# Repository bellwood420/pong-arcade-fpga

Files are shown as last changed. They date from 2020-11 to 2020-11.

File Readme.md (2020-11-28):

# Arcade Pong(1972) on FPGA
Original arcade version Pong(1972) by Atari implemented on FPGA with external analog circuit. 

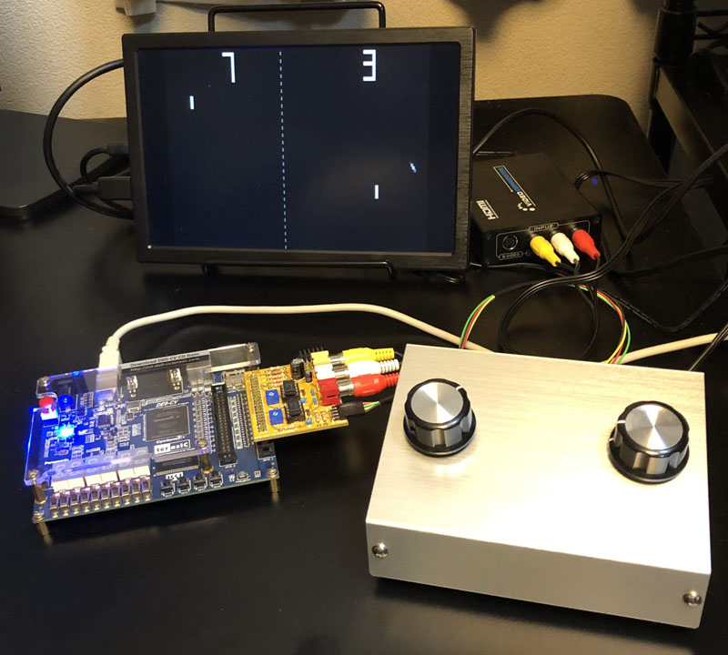
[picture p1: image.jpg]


# Features

## 1. Synchronous drive

The original circuit consists of so many asynchronous aspects, causing unstability both in routing and running on FPGA.  

To avoid it, I implemented whole circuit synchronously by treating clock signals to registers as datapaths for edge detection,
and driving them by main clock.  

This technique is introduced in the [Reference 1](#References)

## 2. Real paddle input

LMC555 and potentiometer on external circuit provide realistic paddle experience.  

Conversely, you cannnot play without them...😇

## 3. Analog video & sound output

RCA connectors on external circuit output NTSC spec video signal and line level sound signal.  

It would be nice to output video signal from VGA connector on typical FPGA boards, but I'm not good enough to make upscaler. 

# Requirements

## External analog circuit
**You need external analog circuit** other than FPGA board to play the game.
- Schematic availabe: pcb/ext-board/ext-board.pdf
- PCB gerber files available: pcb/ext-board/gerber/
- You can build it on breadboard, universal board or use my PCB.
- PCB has 40-pins GPIO connector for Terasic FPGA boards and 12-pins Pmod connector for Digilent FPGA boards.

## FPGA board

Example project files available for the boards below:

<table>
  <tr>
    <th align="left">Board</th>
    <th align="left">Terasic<br>DE0-CV</th>
    <th align="left">Terasic<br>DE-10 Nano</th>
    <th align="left">Digilent<br>Nexys4 DDR</th>
    <th></th>
  </tr>
  <tr>
    <td>Chip</td>
    <td colspan="2">Intel/Altera Cyclone V</td>
    <td>Xilinx Artix-7</td>
    <td></td>
  </tr>
  <tr>
    <td>IDE version</td>
    <td colspan="2">Quartus Prime Lite Edition 20.1</td>
    <td>Vivado 2020.1</td>
    <td></td>
  </tr>
  <tr>
    <td>Start button<br>(COIN_SW)</td>
    <td colspan="2">KEY0</td>
    <td>BTNC</td>
    <td></td>
  </tr>
  <tr>
    <td>Max point sel<br>(SW1A/SW1B)</td>
    <td colspan="3">SW[0]/SW[1]</td>
    <td>On: 15 pts, Off 11 pts</td>
  </tr>
  <tr>
    <td>Connector</td>
    <td>GPIO1</td>
    <td>GPIO0</td>
    <td>Pmod A</td>
    <td>See schematics or qsf/xdc for details</td>
  </tr>
</table>

# References
Without the following documents, I would not have been able to finish this project and understand the mystery of a video game built only on discrete logic ICs. 

1. Stephen A. Edwards. Reconstructing Pong on an FPGA. 2012.  
  http://www.cs.columbia.edu/~sedwards/papers/edwards2012reconstructing.pdf
2. Hugo R. Holden. ATARI PONG E CIRCUIT ANALYSIS & LAWN TENNIS: BUILDING A DIGITAL VIDEO GAME WITH 74 SERIES TTL IC’s. 2013.  
  http://worldphaco.com/uploads/LAWN_TENNIS.pdf

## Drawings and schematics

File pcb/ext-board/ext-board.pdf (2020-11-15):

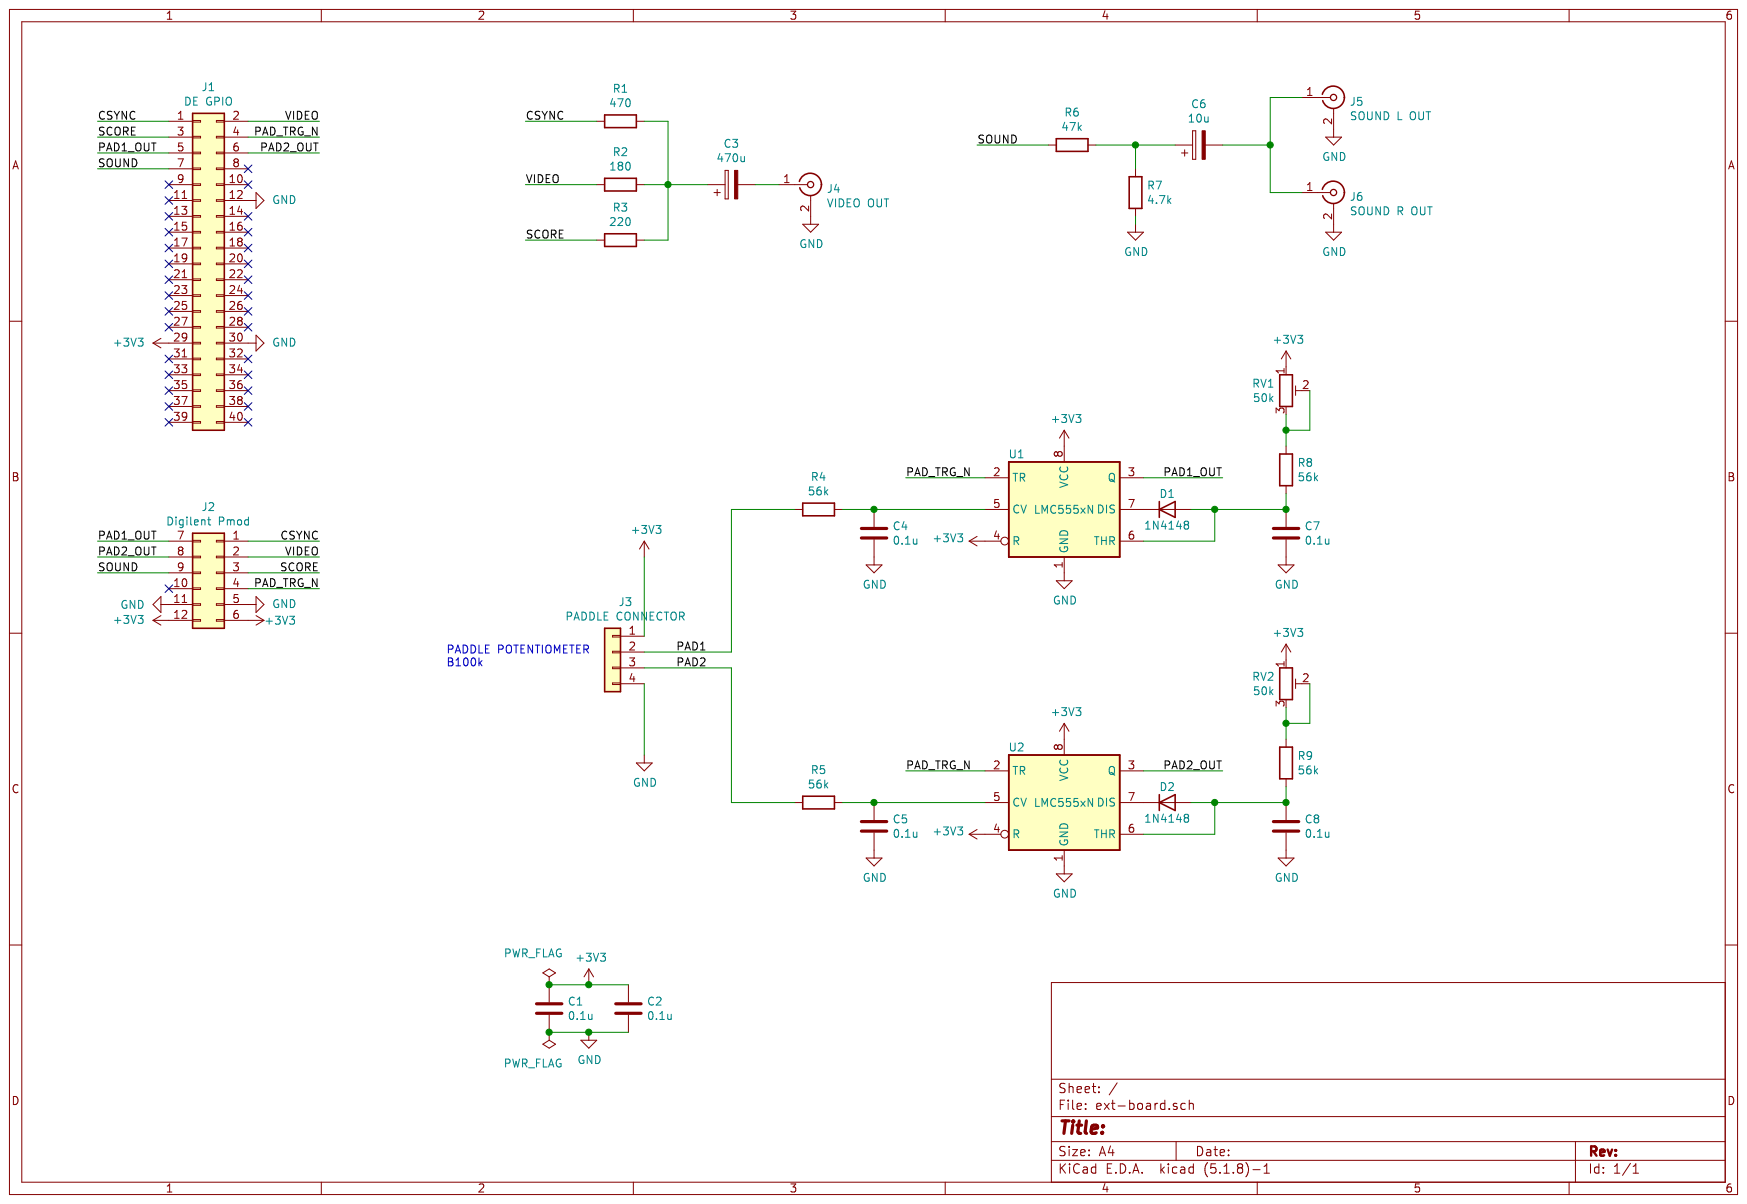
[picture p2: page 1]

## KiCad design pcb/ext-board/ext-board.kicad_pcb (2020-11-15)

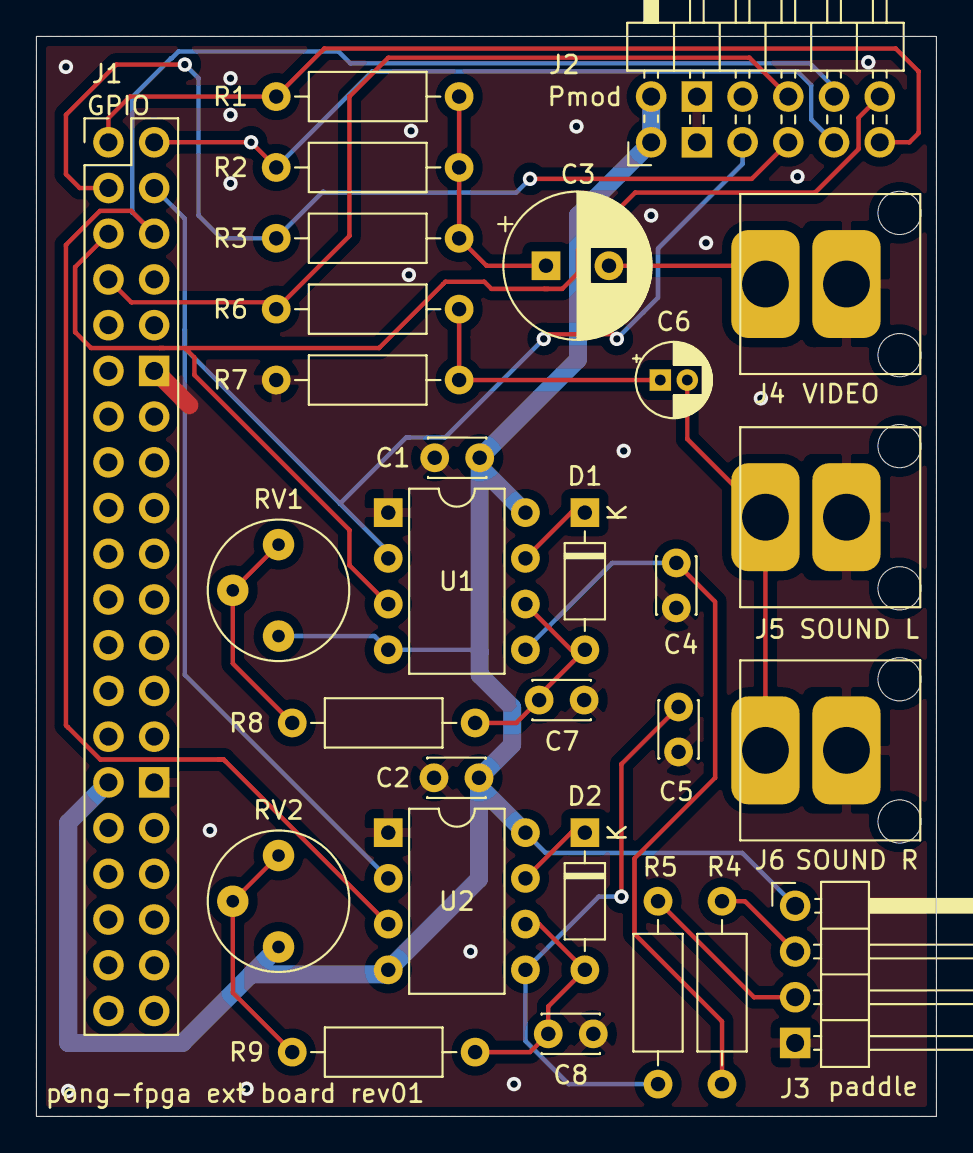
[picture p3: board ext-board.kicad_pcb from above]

Board: 2 copper layers, 50.0 x 60.0 mm, 29 parts (0 on the bottom side), 23 nets.

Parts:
C1, C2, C4, C5, C7, C8: 0.1u; C_Disc_D3.0mm_W2.0mm_P2.50mm
C3: 470u; CP_Radial_D8.0mm_P3.50mm
C6: 10u; CP_Radial_D4.0mm_P1.50mm
D1, D2: 1N4148; D_DO-35_SOD27_P7.62mm_Horizontal
J1: DE GPIO; PinHeader_2x20_P2.54mm_Vertical
J2: Digilent Pmod; PmodConnector
J3: PADDLE CONNECTOR; PinHeader_1x04_P2.54mm_Horizontal
J4: VIDEO OUT; RJ-2410N
J5: SOUND L OUT; RJ-2410N
J6: SOUND R OUT; RJ-2410N
R1, R4, R5: 470; R_Axial_DIN0207_L6.3mm_D2.5mm_P10.16mm_Horizontal
R2: 180; R_Axial_DIN0207_L6.3mm_D2.5mm_P10.16mm_Horizontal
R3: 220; R_Axial_DIN0207_L6.3mm_D2.5mm_P10.16mm_Horizontal
R6: 47k; R_Axial_DIN0207_L6.3mm_D2.5mm_P10.16mm_Horizontal
R7: 4.7k; R_Axial_DIN0207_L6.3mm_D2.5mm_P10.16mm_Horizontal
R8, R9: 56k; R_Axial_DIN0207_L6.3mm_D2.5mm_P10.16mm_Horizontal
RV1, RV2: 50k; Potentiometer_Bourns_3339P_Vertical_HandSoldering
U1, U2: LMC555xN; DIP-8_W7.62mm

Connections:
+3V3: C1.2, C2.2, J1.29, J2.6, J2.12, J3.1, RV1.1, RV2.1, U1.4, U1.8, U2.4, U2.8
/CSYNC: J1.1, J2.1, R1.2
/PAD1: J3.2, R4.2
/PAD1_OUT: J1.5, J2.7, U1.3
/PAD2: J3.3, R5.2
/PAD2_OUT: J1.6, J2.8, U2.3
/PAD_TRG_N: J1.4, J2.4, U1.2, U2.2
/SCORE: J1.3, J2.3, R3.2
/SOUND: J1.7, J2.9, R6.2
/VIDEO: J1.2, J2.2, R2.2
GND: C1.1, C2.1, C4.2, C5.2, C7.2, C8.2, J1.12, J1.30, J2.5, J2.11, J3.4, J4.2, J5.2, J6.2, R7.2, U1.1, U2.1
unnamed: C3.1, R1.1, R2.1, R3.1
unnamed: C3.2, J4.1
unnamed: C4.1, R4.1, U1.5
unnamed: C5.1, R5.1, U2.5
unnamed: C6.1, R6.1, R7.1
unnamed: C6.2, J5.1, J6.1
unnamed: C7.1, D1.2, R8.2, U1.6
unnamed: C8.1, D2.2, R9.2, U2.6
unnamed: D1.1, U1.7
unnamed: D2.1, U2.7
unnamed: R8.1, RV1.2, RV1.3
unnamed: R9.1, RV2.2, RV2.3

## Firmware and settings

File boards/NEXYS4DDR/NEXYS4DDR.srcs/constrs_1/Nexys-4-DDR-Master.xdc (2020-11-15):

## This file is a general .xdc for the Nexys4 DDR Rev. C
## To use it in a project:
## - uncomment the lines corresponding to used pins
## - rename the used ports (in each line, after get_ports) according to the top level signal names in the project

## Avoid warning
set_property CONFIG_VOLTAGE 3.3 [current_design]
set_property CFGBVS VCCO [current_design]


## Clock signal
set_property -dict { PACKAGE_PIN E3    IOSTANDARD LVCMOS33 } [get_ports { CLK100MHZ }]; #IO_L12P_T1_MRCC_35 Sch=clk100mhz
create_clock -add -name sys_clk_pin -period 10.00 -waveform {0 5} [get_ports {CLK100MHZ}];

## Constraints
create_generated_clock -name CLK_PCK -source [get_pins {CLK_PCK_reg/C}] -divide_by 2 [get_pins {CLK_PCK_reg/Q}]

set_false_path -from [get_ports {RESET_N}]
set_false_path -from [get_ports {COIN_SW}]
set_false_path -from [get_ports {SW1A}]
set_false_path -from [get_ports {SW1B}]
set_false_path -from [get_ports {PAD1_OUT}]
set_false_path -from [get_ports {PAD2_OUT}]

set_false_path -to [get_ports {CSYNC}]
set_false_path -to [get_ports {VIDEO}]
set_false_path -to [get_ports {SCORE}]
set_false_path -to [get_ports {PAD_TRG_N}]
set_false_path -to [get_ports {SOUND}]

set_false_path -from [get_pins {reset_sync/q2_reg/C}]

##Switches

set_property -dict { PACKAGE_PIN J15   IOSTANDARD LVCMOS33 } [get_ports { SW1A }]; #IO_L24N_T3_RS0_15 Sch=sw[0]
set_property -dict { PACKAGE_PIN L16   IOSTANDARD LVCMOS33 } [get_ports { SW1B }]; #IO_L3N_T0_DQS_EMCCLK_14 Sch=sw[1]
#set_property -dict { PACKAGE_PIN M13   IOSTANDARD LVCMOS33 } [get_ports { SW[2] }]; #IO_L6N_T0_D08_VREF_14 Sch=sw[2]
#set_property -dict { PACKAGE_PIN R15   IOSTANDARD LVCMOS33 } [get_ports { SW[3] }]; #IO_L13N_T2_MRCC_14 Sch=sw[3]
#set_property -dict { PACKAGE_PIN R17   IOSTANDARD LVCMOS33 } [get_ports { SW[4] }]; #IO_L12N_T1_MRCC_14 Sch=sw[4]
#set_property -dict { PACKAGE_PIN T18   IOSTANDARD LVCMOS33 } [get_ports { SW[5] }]; #IO_L7N_T1_D10_14 Sch=sw[5]
#set_property -dict { PACKAGE_PIN U18   IOSTANDARD LVCMOS33 } [get_ports { SW[6] }]; #IO_L17N_T2_A13_D29_14 Sch=sw[6]
#set_property -dict { PACKAGE_PIN R13   IOSTANDARD LVCMOS33 } [get_ports { SW[7] }]; #IO_L5N_T0_D07_14 Sch=sw[7]
#set_property -dict { PACKAGE_PIN T8    IOSTANDARD LVCMOS18 } [get_ports { SW[8] }]; #IO_L24N_T3_34 Sch=sw[8]
#set_property -dict { PACKAGE_PIN U8    IOSTANDARD LVCMOS18 } [get_ports { SW[9] }]; #IO_25_34 Sch=sw[9]
#set_property -dict { PACKAGE_PIN R16   IOSTANDARD LVCMOS33 } [get_ports { SW[10] }]; #IO_L15P_T2_DQS_RDWR_B_14 Sch=sw[10]
#set_property -dict { PACKAGE_PIN T13   IOSTANDARD LVCMOS33 } [get_ports { SW[11] }]; #IO_L23P_T3_A03_D19_14 Sch=sw[11]
#set_property -dict { PACKAGE_PIN H6    IOSTANDARD LVCMOS33 } [get_ports { SW[12] }]; #IO_L24P_T3_35 Sch=sw[12]
#set_property -dict { PACKAGE_PIN U12   IOSTANDARD LVCMOS33 } [get_ports { SW[13] }]; #IO_L20P_T3_A08_D24_14 Sch=sw[13]
#set_property -dict { PACKAGE_PIN U11   IOSTANDARD LVCMOS33 } [get_ports { SW[14] }]; #IO_L19N_T3_A09_D25_VREF_14 Sch=sw[14]
#set_property -dict { PACKAGE_PIN V10   IOSTANDARD LVCMOS33 } [get_ports { SW[15] }]; #IO_L21P_T3_DQS_14 Sch=sw[15]


## LEDs
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
